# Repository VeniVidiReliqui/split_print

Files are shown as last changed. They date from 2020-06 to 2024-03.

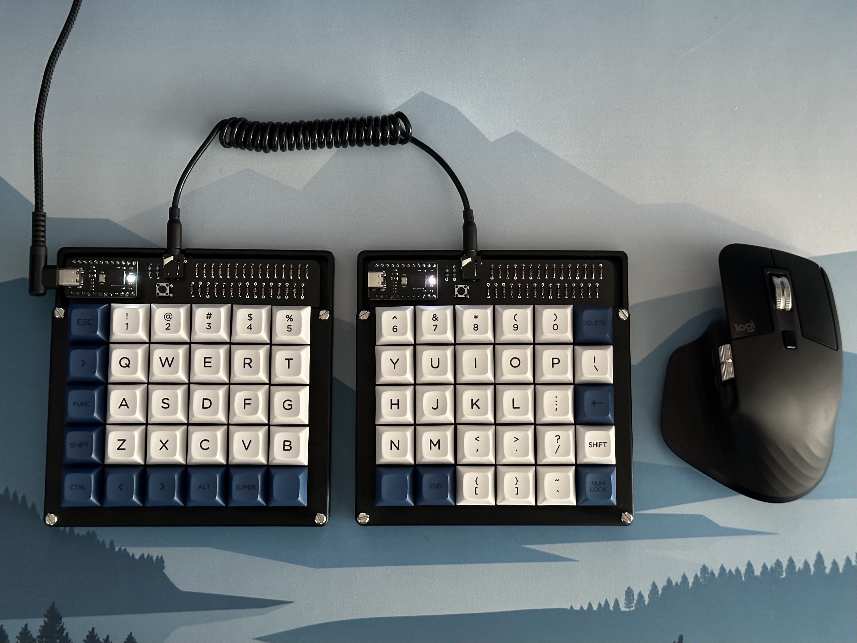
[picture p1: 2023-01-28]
pics/IMG_8846.jpeg

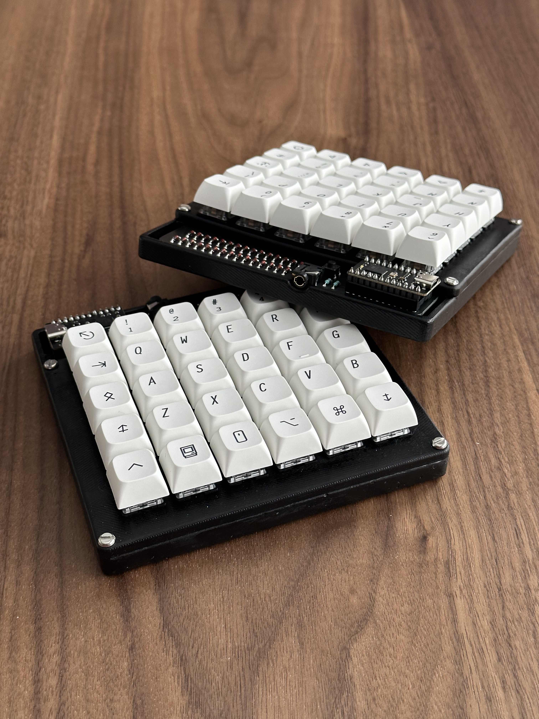
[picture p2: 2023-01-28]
pics/IMG_8842.jpeg

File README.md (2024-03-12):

# Split_Print
This is a split, top-mounted, ortholinear keyboard I built to use with QMK firmware and the Pro Micro compatible Bit-C. This repo contains step files for the keyboard case, gerber files for the PCB, and the keymap I'm currently using. Read further for building instructions, parts list, and tips I recommend while building this keyboard.

## Repo Contents
Here's a quick breakdown of what you'll find here:

+ 3D print models
    + case
        - base_hotswap_v*.stl -> single case base, version number might vary
        - plate_hotswap_v*.stl -> switch plate, version number might vary
    + misc
        - keycap_standard.stl -> custom cherry chiclet keycap (I don't recommend using these)
        - keycap_with_nub.stl -> same as keycap_standard but with F and J nub to identify home row
        - wrist_rest.stl -> optional wrist rest
- split_print -> keymap and make files to build firmware with QMK
- pics -> pictures of my own build
- Keyboard_pcb_gerber.zip -> all necessary gerber files to fabricate PCB

## Printing Components
For a full build of this keyboard you'll need to print:

- 2 base_hotswap_v*
- 2 plate_hotswap_v*
- 2 wrist_rests (optional)
- 58 keycap_standard (optional, not recommended)
- 2 keycap_with_nub for F and J keys (optional, not recommended)

General Notes:

- Remember to *hollow out* the wrist rest to your desired thickness or you'll waste a lot of material.
- I found the case parts print best with support structures interfacing mainly with the bottom face of the case. The flat bottom face is much easier to sand than the interior of the case.
- The keycaps print better with the stem pointing toward the build plate. This provided for a smooth typing surface and helps keep the stem from warping.
- If you don't intend to paint them, quick rub-down with some mineral oil can help give the parts a nice finish after sanding.

## Printing PCBs
Okay so you probably won't be printing this PCB yourself, but it also shouldn't be expensive to order it from one of the many fabrication shops. I used [JLCPCB](https://jlcpcb.com) because they linked directly from [EasyEDA](https://easyeda.com), the design software I used to create the layout. In all 10 boards cost me less than $30, but your mileage may vary. **You'll need 2 PCBs total**, one for each half of the keyboard.

## Electronics and Other Hardware
The build obviously requires more hardware and electrical components than I can provide in this repo. You'll need a **soldering iron** for the electrical components, but I'm assuming you already have one. Here are the other necessary components with the respective DigiKey, McMaster-Carr, etc part I used:

- (2) [Nullbits Bit-C](https://nullbits.co/bit-c/) or any equivalent [Pro Micro](https://www.sparkfun.com/products/12640)
- (2) IC Sockets (optional) [ICS-624-T](https://www.digikey.com/en/products/detail/adam-tech/ICS-624-T/9832867)
- (4) 12pos 1 row headers for Pro Micro [DK# 2057-PH1-12-UA-ND](https://www.digikey.com/product-detail/en/adam-tech/PH1-12-UA/2057-PH1-12-UA-ND/9830395)
- (2) Reset Buttons [TS02-66-55-BK-160-LCR-D](https://www.digikey.com/en/products/detail/cui-devices/TS02-66-55-BK-160-LCR-D/15634374)
- (4) 4.7kOhm Resistors, for pullup on I2C [DK# S4.7KCACT-ND](https://www.digikey.com/product-detail/en/stackpole-electronics-inc/RNMF14FTC4K70/S4.7KCACT-ND/2617510)
- (2) TRRS Jacks [DK# CP-43515TS-ND](https://www.digikey.com/product-detail/en/cui-devices/SJ-43515TS/CP-43515TS-ND/368147)
- (60) 1N4148 Diodes [DK# 1N4148FS-ND](https://www.digikey.com/product-detail/en/on-semiconductor/1N4148/1N4148FS-ND/458603)
- (8) M3 x 0.5mm thread 12mm long standard pan-head screw [MMC# 91200A118](https://www.mcmaster.com/catalog/91200A118)
- (8) M3 x 0.5mm thread nut [MMC# 91828A211](https://www.mcmaster.com/catalog/91828A211)

You'll need a **USB-C cable** to connect the left half to the computer and a **TRRS cable** to connect the two halves of the keyboard. I recommend a right-angled USB cable since the microcontroller is sideways on the PCB, and a coiled TRRS cable. These can be found at most electronics stores or Amazon.

You may also want rubber feet on the bottom of the keyboard and wrist rests. I recommend clear picture bumpers because they're cheap and provide decent grip on most desk surfaces.

## Keyswitches? Keycaps?
Oh yeah, your keyboard won't work without keyswitches. But If you're going to all this effort, you probably knew that. If you know what you're doing,  be sure to get **60 Cherry Mx-style, plate-mount switches**. Note if you want to try the chiclet keycaps, I only tested them with the standard cherry stem; I can't guarantee they will work with box or similar switch stems. Also the PCB doesn't support any RGB, sorry gamers.

If you're less familiar with keyswitches, I suggest grabbing a keyswitch tester and checking out [this switch intro article](https://www.keyboardco.com/blog/index.php/2012/12/an-introduction-to-cherry-mx-mechanical-switches/) to get an idea of what you will want. It's important to determine the tactility you prefer ahead of buying an entire set of switches, although the hotswap sockets in this board make it easier to replace them in the future.

I used linear Gateron Black switches for this build and have tactile "Holy Panda"-style switches in my work keyboard. If you want to go that extra mile, grab some Krytox 205G0 lubricant and find a tutorial on how to lube the switches. It takes time and some patience, but your fingers will appreciate it.

You'll also need keycaps, but I'll let you explore this. These are incredibly subjective since they'll help drive the aesthetic and sound of the board. I recommend [reading a guide on keycaps](https://switchandclick.com/ultimate-guide-to-picking-a-keycap-set-for-your-mechanical-keyboard/) to better understand how the shapes and materials affect the typing experience. 

## Building Keyboard
Once you have all the components, I suggest following this order to assemble the keyboard for the easiest build. Going forward, the "Designed By" label will signify the top of the PCB:

1. Solder the hotswap sockets to the pads on the bottom of the PCB. I recommend adding a small amount of solder to the pad before laying the socket down.
2. Solder 30 of the diodes into the through-holes in the top right section of the PCB. The diodes should be on the top, with the legs going through to the bottom. Be sure to orient each diode so the cathode (side with the black ring) is pointed away from the keyswitch area.
3. Solder the TRRS jack to the 5 through-holes to the left of the diode array. You can use electrical tape to hold it flat to the PCB while you solder.
4. Solder the reset button below the TRRS jack. I had to straighten the legs with pliers before they would fit into the holes.
5. Solder two 4.7k resistors to the left of the TRRS jack. Orientation doesn't matter, but I like to match the direction of the colored rings so it looks nice.
6. Solder headers to the Pro Micro and solder it (or the IC Socket) to the top-left of the PCB so the USB port is pointing away from the diodes. If you are using the IC Socket, you can stick the headers in the socket to stabilize them while soldering them to the Pro Micro.
7. Place the top plate onto the PCB and snap in 30 switches onto the board. Be careful that you don't bend the legs of the switches doing this.
8. Put plate half onto the case and bolt them together. 

## Building Firmware
Once the keyboard is built, you'll need to program it. To use the keymap I've included, you'll need to setup the [QMK Firmware project](https://github.com/qmk/qmk_firmware) to build and flash the firmware to your Bit-C or Pro Micro. Once this is done, you'll need to manually copy the layout and config files to the appropriate location in qmk_firmware:

1. Copy the split_print folder to qmk_firmware/keyboards/. Alternatively, create a symlink from within the qmk_firmware/keyboards/ directory to the split_print directory in this repo.

2. Build the firmware in /qmk_firmware:

```qmk compile -kb split_print -km default```

3. Flash the firmware in /qmk_firmware to each keyboard half. You MUST flash each keyboard individually! I make sure to connect to each half directly, with the TRRS cable unplugged. Also, be sure to check the bootloader if you're using a [different microcontroller)(https://github.com/qmk/qmk_firmware/blob/master/docs/feature_split_keyboard.md).

```qmk flash -kb split_print -km default -bl dfu-split-left```

or

```qmk flash -kb split_print -km default -bl dfu-split-right```

If you want to modify the keymap.c for your own custom layout, checkout the [QMK keycodes](https://github.com/qmk/qmk_firmware/blob/master/docs/keycodes.md) so you know what to add into the keymap.

## Areas of Improvement
This will be an evolving project with each keyboard I build, so I'm tracking things to address in future builds below.

- Ergonomics could be a greater consideration, with the case angled to improve the typing experience. I'm toying with printable tenting pieces that could adjust the typing angle. A metal plate in the case and magnets embedded in the printable tent accessories could make this easily customizable.

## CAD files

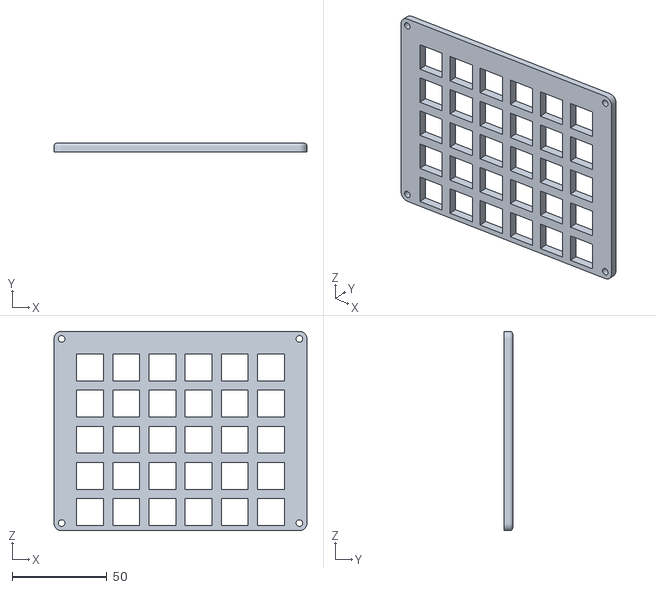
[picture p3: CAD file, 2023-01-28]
3D print models/case/plate_hotswap_v2.stl
133.2 x 4.50 x 105.0

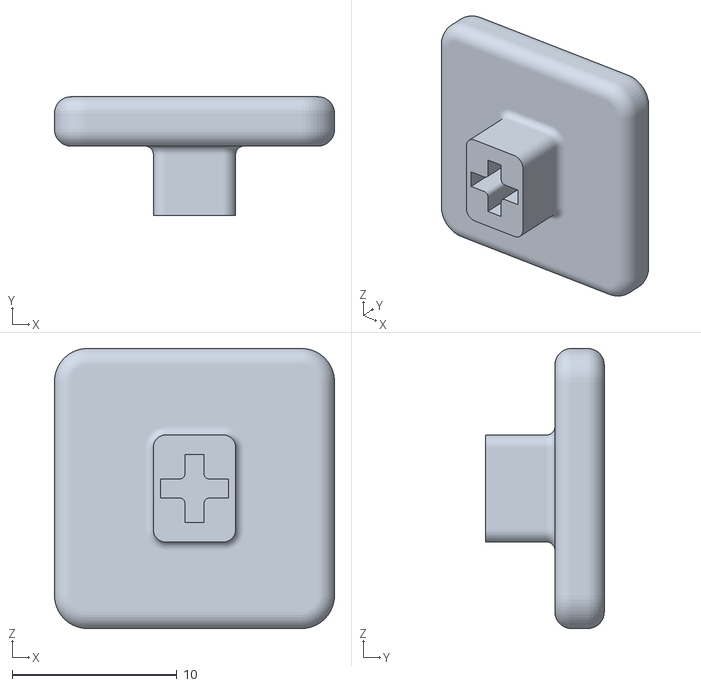
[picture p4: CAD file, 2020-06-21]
3D print models/misc/keycap_standard.stl
17.0 x 7.20 x 17.0

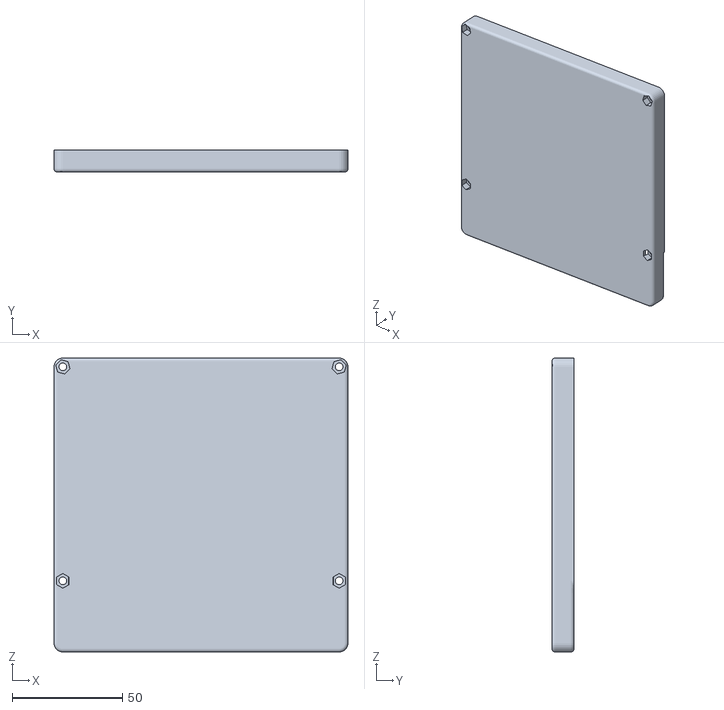
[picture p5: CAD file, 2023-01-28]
3D print models/case/base_hotswap_v8.stl
133.2 x 10.0 x 133.2

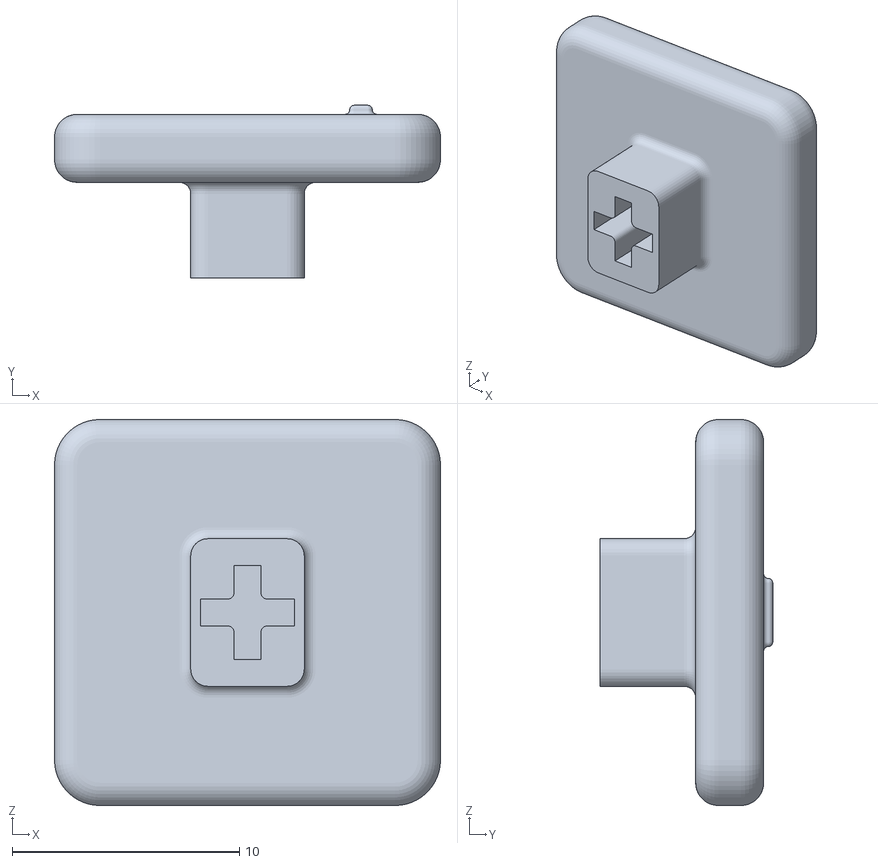
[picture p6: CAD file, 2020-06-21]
3D print models/misc/keycap_with_nub.stl
17.0 x 7.60 x 17.0

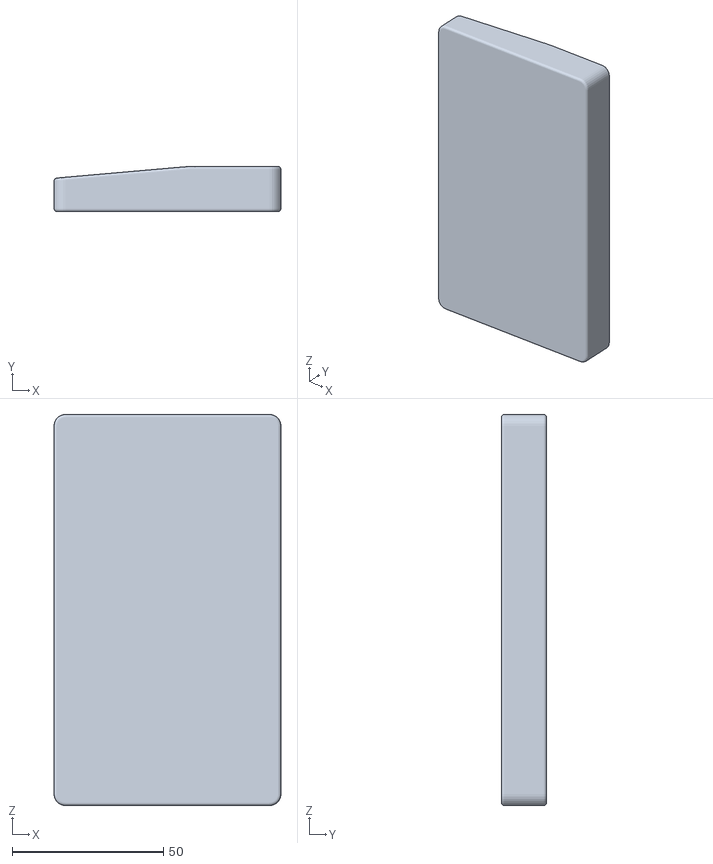
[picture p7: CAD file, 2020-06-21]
3D print models/misc/wrist_rest.stl
75.0 x 15.0 x 129.2

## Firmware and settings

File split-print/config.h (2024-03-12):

#ifndef CONFIG_H
#define CONFIG_H

/* key matrix size */
#define MATRIX_ROWS 10
#define MATRIX_COLS 6

/* key combination for command */
#define IS_COMMAND() ( \
    keyboard_report->mods == (MOD_BIT(KC_LSHIFT) | MOD_BIT(KC_RSHIFT)) \
)

/* Mouse configuration */
//#define MK_3_SPEED                        // Enable constant cursor speeds
//#define MK_KINETIC_SPEED                    // Enable quadratic cursor movement

#ifdef MK_3_SPEED
/* Constant cursor mouse settings */
#define MOUSEKEY_DELAY              5       // Delay between pressing a movement key and cursor movement
#define MOUSEKEY_INTERVAL           10      // Time between cursor movements in milliseconds
#define MOUSEKEY_MOVE_DELTA         5       // Step size
#define MOUSEKEY_MAX_SPEED          5       // Maximum cursor speed at which acceleration stops
#define MOUSEKEY_TIME_TO_MAX        100     // Time until maximum cursor speed is reached
/* Mouse Wheel settings */
#define MOUSEKEY_WHEEL_DELAY        10      // Delay between pressing a wheel key and wheel movement
#define MOUSEKEY_WHEEL_INTERVAL     80      // Time between wheel movements
#define MOUSEKEY_WHEEL_MAX_SPEED    8       // Maximum number of scroll steps per scroll action
#define MOUSEKEY_WHEEL_TIME_TO_MAX  40      // Time until maximum scroll speed is reached
#endif /*MK_3_SPEED*/

#ifdef MK_KINETIC_SPEED
/* Kinetic cursor mouse settings */
#define MOUSEKEY_DELAY                          5       // Delay between pressing a movement key and cursor movement
#define MOUSEKEY_INTERVAL                       10      // Time between cursor movements in milliseconds
#define MOUSEKEY_MOVE_DELTA                     2       // Step size
#define MOUSEKEY_INITIAL_SPEED                  100     // Iinitial speed of the cursor in pixel per second
#define MOUSEKEY_BASE_SPEED                     500     // Maximum cursor speed at which acceleration stops
#define MOUSEKEY_DECELERATED_SPEED              400     // Decelerated cursor speed
#define MOUSEKEY_ACCELERATED_SPEED              3000    // Accelerated cursor speed
/* Mouse wheel settings */
#define MOUSEKEY_WHEEL_INITIAL_MOVEMENTS        16      // Initial number of movements of the mouse wheel
#define MOUSEKEY_WHEEL_BASE_MOVEMENTS           32      // Maximum number of movements at which acceleration stops
#define MOUSEKEY_WHEEL_ACCELERATED_MOVEMENTS    48      // Accelerated wheel movements
#define MOUSEKEY_WHEEL_DECELERATED_MOVEMENTS    8       // Decelerated wheel movements
#endif /*MK_KINETIC_SPEED*/

//#define F_SCL                   400000L // default
#define USE_I2C

/* Auto-detect the Left half, which will be plugged into computer. If you want
 * to power the split keyboard with the right half, you need to modify the hand
 * configuration below
 *
 * Note: This can cause issues with powered USB hubs. If power is delivered
 * to the keyboard but the computer isn't detected, this leads to both halves
 * booting into right hand mode. A power cycle of the keyboards while a computer is 
 * connected to them will fix this.
 *
 * If you run into this issue, and can't use EEPROM bootloader configuration, 
 * consider defining the MASTER_LEFT and MASTER_RIGHT options manually.
 */
//#define SPLIT_USB_DETECT

#ifdef SPLIT_USB_DETECT
#define SPLIT_USB_TIMEOUT       1000    // How long to wait before booting into right hand mode
#define SPLIT_USB_TIMEOUT_POLL  10      // Poll rate to detect left/right hand mode

/* Select hand configuration */
#define MASTER_LEFT
//#define MASTER_RIGHT

#endif

#ifndef SPLIT_USB_DETECT
#define EE_HANDS  // flag eeprom for split half bootloader
#endif

#endif

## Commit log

2020-06-21 Add first version of everything.
    [case_left_dovetail.stl, case_right_dovetail.stl, keycap_standard.stl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]
2020-08-02 Update everything to include rev2 updates
    [base_v2_single.stl, case_v1_left_dovetail.stl, case_v1_right_dovetail.stl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]
2020-12-11 Update keymap, shorten split usb timeout.
    [config.h]
2021-10-08 Swap layer 3 toggle and momentary buttons. This makes one-handed numpad use easier and two-handed numpad use require holding the left-hand layer modifier.
2022-06-26 Update readme to replace Teensy with Pro Micro and to use the Pro Micro flashing procedure.
2022-06-26 Update gerber files with new PCB for Pro Micro.
2023-01-28 Fix minor compilation errors, add clarifying comments.
    [config.h]
2023-01-28 Add latest STL for case, remove old STL for Teensy version of build.
    [base_hotswap_v8.stl, base_v2_single.stl, case_v1_left_dovetail.stl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]
2024-03-12 Revert folder name to match QMK naming conventions.(
    [config.h]
